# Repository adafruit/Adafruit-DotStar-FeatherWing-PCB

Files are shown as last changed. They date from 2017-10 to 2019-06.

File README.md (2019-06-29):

## Adafruit DotStar FeatherWing PCB

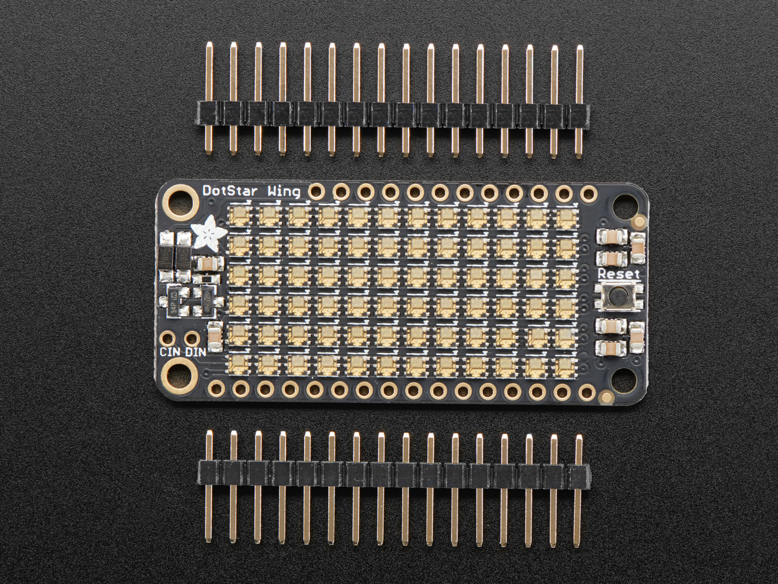
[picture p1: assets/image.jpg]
<a href="http://www.adafruit.com/products/3449"><br/>
Click here to purchase one from the Adafruit shop</a>

PCB files for the Adafruit DotStar FeatherWing. Format is EagleCAD schematic and board layout

For more details, check out the product page at
* http://www.adafruit.com/products/3449

### Description

A Feather board without ambition is a Feather board without FeatherWings! This is the DotStar FeatherWing, a 6x12 RGB LED Add-on For All Feather Boards! Using our Feather Stacking Headers or Feather Female Headers you can connect a FeatherWing on top or bottom of your Feather board and make your Feather board strut like a peacock at a rave.

Put on your sunglasses before staring into these 72 configurable RGB LEDs, they are super bright! Arranged in a 6x12 matrix, each 2mm by 2mm sized RGB pixel is individually addressable. Only two pins are required to control all the LEDs. On the bottom we have jumpers for the Data and Clock lines so you can change them from the defaults. Works with any/all of our Feathers! You can cut the default jumper traces and use any pins you like

To make it easy to start, the LEDs are by default powered from either the USB power line or Battery power line, whichever is higher. Two Schottky diodes are used to switch between the two. This power arrangement is able to handle 1 Amp of constant current draw and maybe 2A peak, so not a good way to make a flashlight. It's better for colorful effects. A power MOSFET is set up and connected to the ENABLE pin on the Feather so that when the Feather is disabled, the wing will also cut power.

### License

Adafruit invests time and resources providing this open source design, please support Adafruit and open-source hardware by purchasing products from [Adafruit](https://www.adafruit.com)!

Designed by Limor Fried/Ladyada for Adafruit Industries.

Creative Commons Attribution/Share-Alike, all text above must be included in any redistribution. See license.txt for additional details.

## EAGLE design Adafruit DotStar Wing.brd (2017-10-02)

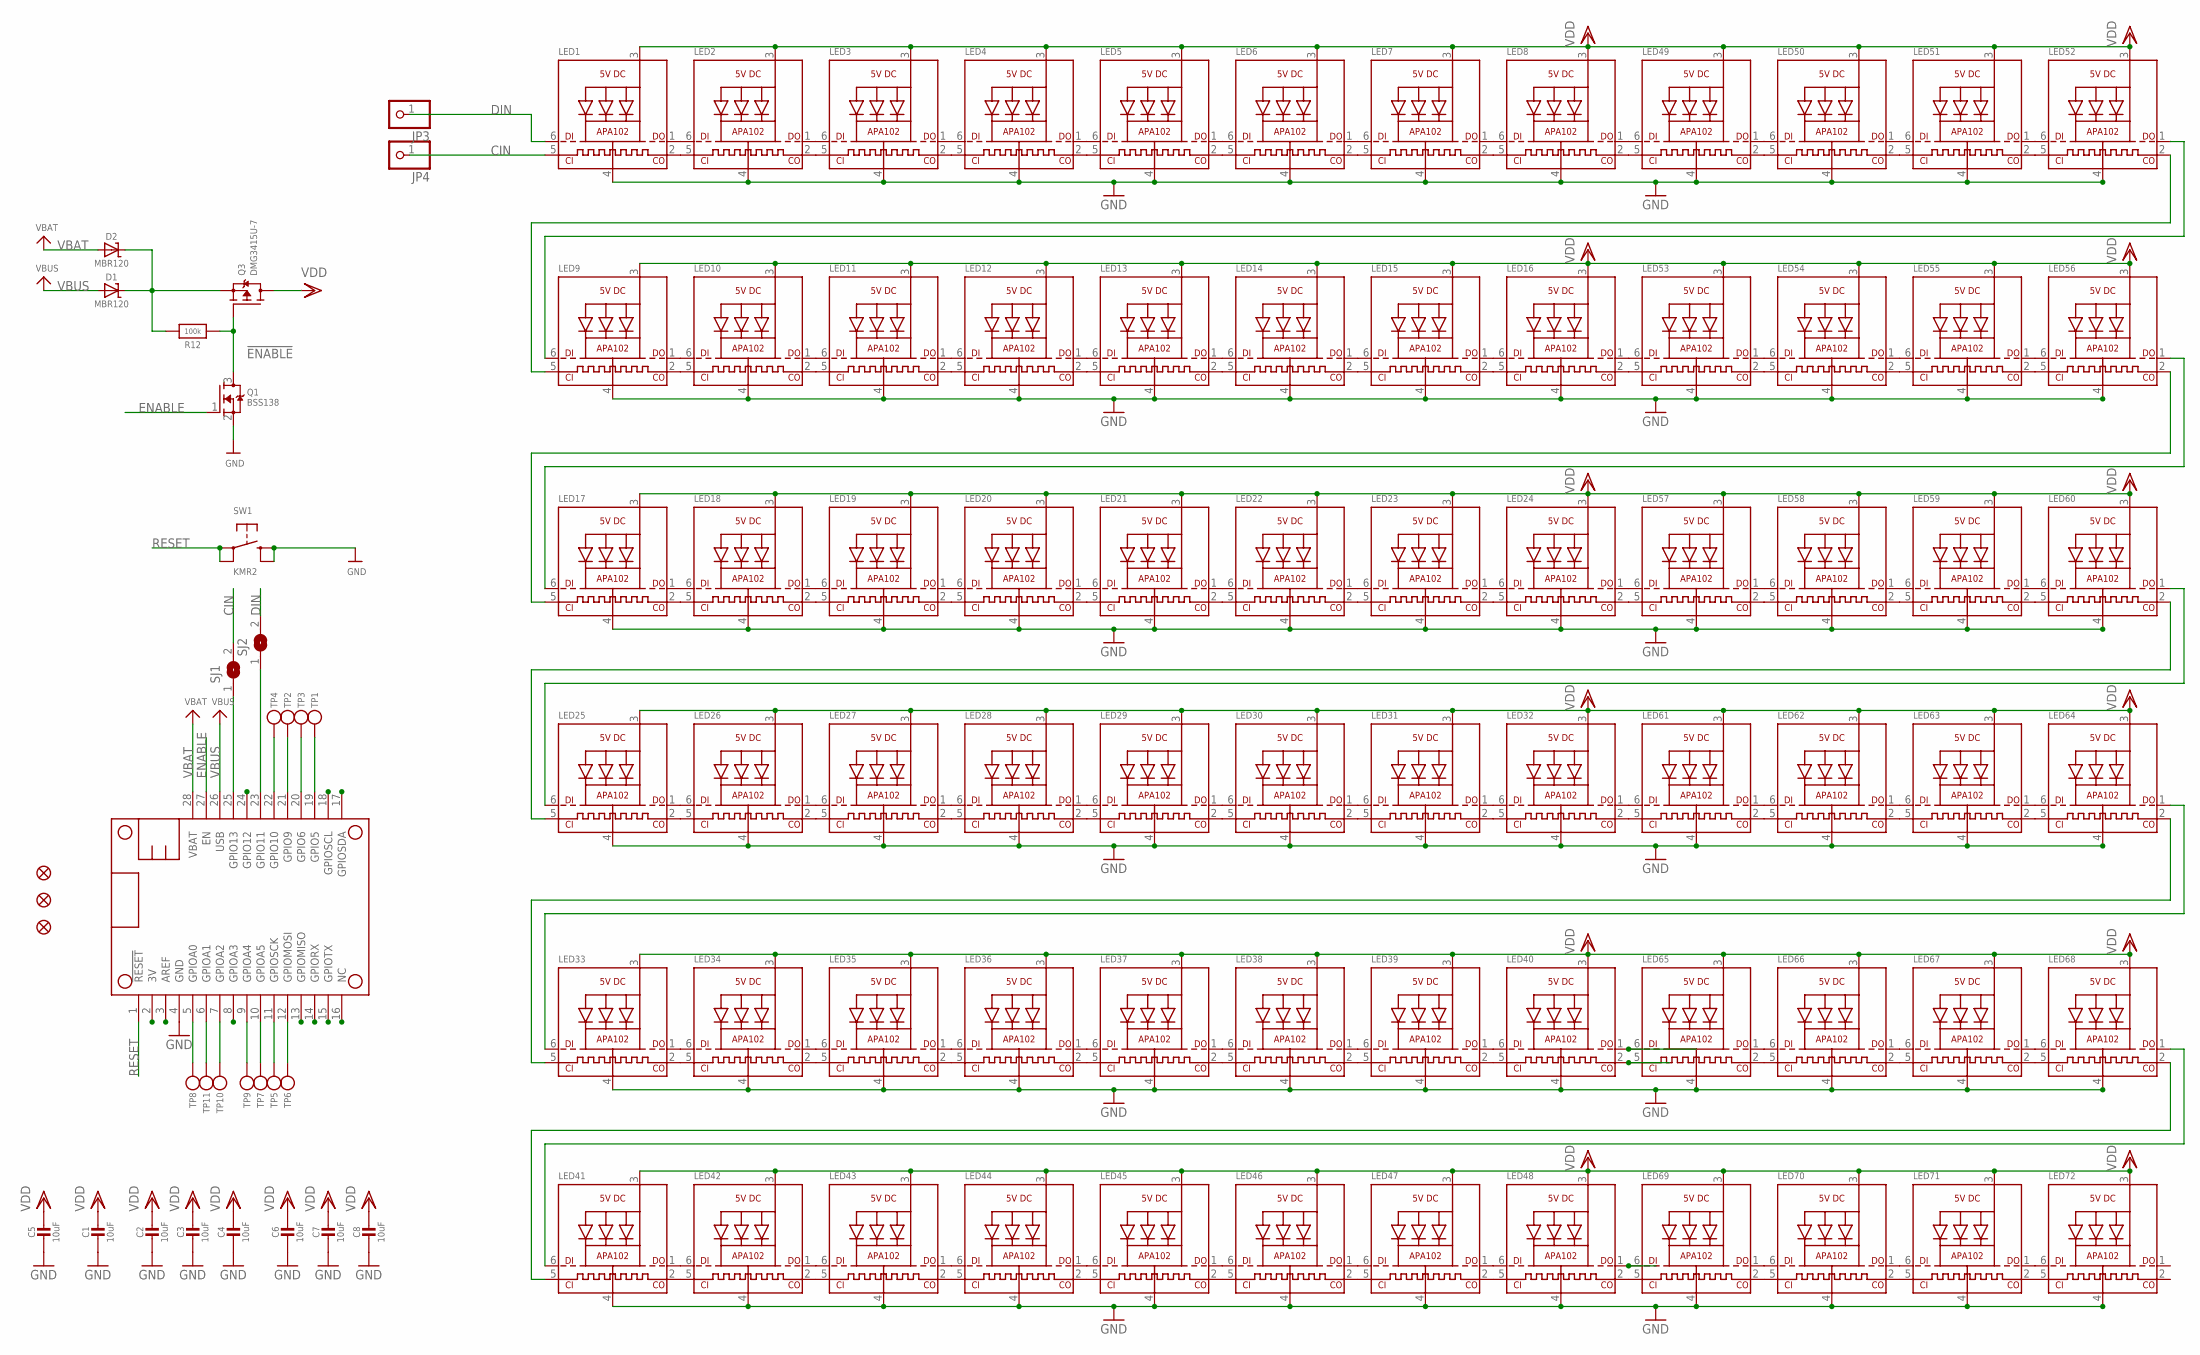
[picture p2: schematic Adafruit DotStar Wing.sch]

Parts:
C1, C2, C3, C4, C5, C6, C7, C8: 10uF; 0805-NO
D1, D2: MBR120; SOD-123
FID1, FID2, FID3: FIDUCIAL_1MM
JP3, JP4: HEADER-1X1ROUND; 1X01_ROUND
LED1, LED2, LED3, LED4, LED5, LED6, LED7, LED8, LED9, LED10, LED11, LED12, LED13, LED14, LED15, LED16, LED17, LED18, LED19, LED20, LED21, LED22, LED23, LED24, LED25, LED26, LED27, LED28, LED29, LED30, LED31, LED32, LED33, LED34, LED35, LED36, LED37, LED38, LED39, LED40, LED41, LED42, LED43, LED44, LED45, LED46, LED47, LED48, LED49, LED50, LED51, LED52, LED53, LED54, LED55, LED56, LED57, LED58, LED59, LED60, LED61, LED62, LED63, LED64, LED65, LED66, LED67, LED68, LED69, LED70, LED71, LED72: APA1022020; APA102_2020
MS1: FEATHERWING
Q1: BSS138; SOT23-WIDE
Q3: DMG3415U-7; SOT23-WIDE
R12: 100k; 0603-NO
SJ1, SJ2: SOLDERJUMPERCLOSED; SOLDERJUMPER_CLOSEDWIRE
SW1: KMR2; BTN_KMR2_4.6X2.8
TP1, TP2, TP3, TP4, TP5, TP6, TP7, TP8, TP9, TP10, TP11: TESTPOINT1.5X2.0MM_NOCREAM; PAD-1.5X2.0

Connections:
3V: MS1.2 (3V)
!ENABLE: Q1.3 (D), Q3.1 (G), R12.1
A0: MS1.5 (GPIOA0), TP8.P$1
A1: MS1.6 (GPIOA1), TP11.P$1
A2: MS1.7 (GPIOA2), TP10.P$1
A3: MS1.8 (GPIOA3)
A4: MS1.9 (GPIOA4), TP9.P$1
A5: MS1.10 (GPIOA5), TP7.P$1
AREF: MS1.3 (AREF)
CIN: JP4.1, LED1.5 (CKI), SJ1.2
DIN: JP3.1, LED1.6 (DI), SJ2.2
ENABLE: MS1.27 (EN), Q1.1 (G)
G: MS1.16 (NC)
GND: C1.2, C2.2, C3.2, C4.2, C5.2, C6.2, C7.2, C8.2, LED1.4 (GND), LED2.4 (GND), LED3.4 (GND), LED4.4 (GND), LED5.4 (GND), LED6.4 (GND), LED7.4 (GND), LED8.4 (GND), LED9.4 (GND), LED10.4 (GND), LED11.4 (GND), LED12.4 (GND), LED13.4 (GND), LED14.4 (GND), LED15.4 (GND), LED16.4 (GND), LED17.4 (GND), LED18.4 (GND), LED19.4 (GND), LED20.4 (GND), LED21.4 (GND), LED22.4 (GND), LED23.4 (GND), LED24.4 (GND), LED25.4 (GND), LED26.4 (GND), LED27.4 (GND), LED28.4 (GND), LED29.4 (GND), LED30.4 (GND), LED31.4 (GND), LED32.4 (GND), LED33.4 (GND), LED34.4 (GND), LED35.4 (GND), LED36.4 (GND), LED37.4 (GND), LED38.4 (GND), LED39.4 (GND), LED40.4 (GND), LED41.4 (GND), LED42.4 (GND), LED43.4 (GND), LED44.4 (GND), LED45.4 (GND), LED46.4 (GND), LED47.4 (GND), LED48.4 (GND), LED49.4 (GND), LED50.4 (GND), LED51.4 (GND), LED52.4 (GND), LED53.4 (GND), LED54.4 (GND), LED55.4 (GND), LED56.4 (GND), LED57.4 (GND), LED58.4 (GND), LED59.4 (GND), LED60.4 (GND), LED61.4 (GND), LED62.4 (GND), LED63.4 (GND), LED64.4 (GND), LED65.4 (GND), LED66.4 (GND), LED67.4 (GND), LED68.4 (GND), LED69.4 (GND), LED70.4 (GND), LED71.4 (GND), LED72.4 (GND), MS1.4 (GND), Q1.2 (S), SW1.B (S), SW1.B' (S1)
H: MS1.19 (GPIO5), TP1.P$1
I: MS1.20 (GPIO6), TP3.P$1
J: MS1.21 (GPIO9), TP2.P$1
K: MS1.22 (GPIO10), TP4.P$1
L: MS1.23 (GPIO11), SJ2.1
M: MS1.24 (GPIO12)
MISO: MS1.13 (GPIOMISO)
MOSI: MS1.12 (GPIOMOSI), TP6.P$1
N: MS1.25 (GPIO13), SJ1.1
unnamed: LED1.1 (DO), LED2.6 (DI)
unnamed: LED1.2 (CKO), LED2.5 (CKI)
unnamed: LED2.1 (DO), LED3.6 (DI)
unnamed: LED2.2 (CKO), LED3.5 (CKI)
unnamed: LED3.1 (DO), LED4.6 (DI)
unnamed: LED3.2 (CKO), LED4.5 (CKI)
unnamed: LED4.1 (DO), LED5.6 (DI)
unnamed: LED4.2 (CKO), LED5.5 (CKI)
unnamed: LED5.1 (DO), LED6.6 (DI)
unnamed: LED5.2 (CKO), LED6.5 (CKI)
unnamed: LED6.1 (DO), LED7.6 (DI)
unnamed: LED6.2 (CKO), LED7.5 (CKI)
unnamed: LED7.1 (DO), LED8.6 (DI)
unnamed: LED7.2 (CKO), LED8.5 (CKI)
unnamed: LED9.1 (DO), LED10.6 (DI)
unnamed: LED9.2 (CKO), LED10.5 (CKI)
unnamed: LED10.1 (DO), LED11.6 (DI)
unnamed: LED10.2 (CKO), LED11.5 (CKI)
unnamed: LED11.1 (DO), LED12.6 (DI)
unnamed: LED11.2 (CKO), LED12.5 (CKI)
unnamed: LED12.1 (DO), LED13.6 (DI)
unnamed: LED12.2 (CKO), LED13.5 (CKI)
unnamed: LED13.1 (DO), LED14.6 (DI)
unnamed: LED13.2 (CKO), LED14.5 (CKI)
unnamed: LED14.1 (DO), LED15.6 (DI)
unnamed: LED14.2 (CKO), LED15.5 (CKI)
unnamed: LED15.1 (DO), LED16.6 (DI)
unnamed: LED15.2 (CKO), LED16.5 (CKI)
unnamed: LED17.1 (DO), LED18.6 (DI)
unnamed: LED17.2 (CKO), LED18.5 (CKI)
unnamed: LED18.1 (DO), LED19.6 (DI)
unnamed: LED18.2 (CKO), LED19.5 (CKI)
unnamed: LED19.1 (DO), LED20.6 (DI)
unnamed: LED19.2 (CKO), LED20.5 (CKI)
unnamed: LED20.1 (DO), LED21.6 (DI)
unnamed: LED20.2 (CKO), LED21.5 (CKI)
unnamed: LED21.1 (DO), LED22.6 (DI)
unnamed: LED21.2 (CKO), LED22.5 (CKI)
unnamed: LED22.1 (DO), LED23.6 (DI)
unnamed: LED22.2 (CKO), LED23.5 (CKI)
unnamed: LED23.1 (DO), LED24.6 (DI)
unnamed: LED23.2 (CKO), LED24.5 (CKI)
unnamed: LED25.1 (DO), LED26.6 (DI)
unnamed: LED25.2 (CKO), LED26.5 (CKI)
unnamed: LED26.1 (DO), LED27.6 (DI)
unnamed: LED26.2 (CKO), LED27.5 (CKI)
unnamed: LED27.1 (DO), LED28.6 (DI)
unnamed: LED27.2 (CKO), LED28.5 (CKI)
unnamed: LED28.1 (DO), LED29.6 (DI)
unnamed: LED28.2 (CKO), LED29.5 (CKI)
unnamed: LED29.1 (DO), LED30.6 (DI)
unnamed: LED29.2 (CKO), LED30.5 (CKI)
unnamed: LED30.1 (DO), LED31.6 (DI)
unnamed: LED30.2 (CKO), LED31.5 (CKI)
unnamed: LED31.1 (DO), LED32.6 (DI)
unnamed: LED31.2 (CKO), LED32.5 (CKI)
unnamed: LED33.1 (DO), LED34.6 (DI)
unnamed: LED33.2 (CKO), LED34.5 (CKI)
unnamed: LED34.1 (DO), LED35.6 (DI)
unnamed: LED34.2 (CKO), LED35.5 (CKI)
unnamed: LED35.1 (DO), LED36.6 (DI)
unnamed: LED35.2 (CKO), LED36.5 (CKI)
unnamed: LED36.1 (DO), LED37.6 (DI)
unnamed: LED36.2 (CKO), LED37.5 (CKI)
unnamed: LED37.1 (DO), LED38.6 (DI)
unnamed: LED37.2 (CKO), LED38.5 (CKI)
unnamed: LED38.1 (DO), LED39.6 (DI)
unnamed: LED38.2 (CKO), LED39.5 (CKI)
unnamed: LED39.1 (DO), LED40.6 (DI)
unnamed: LED39.2 (CKO), LED40.5 (CKI)
unnamed: LED41.1 (DO), LED42.6 (DI)
unnamed: LED41.2 (CKO), LED42.5 (CKI)
unnamed: LED42.1 (DO), LED43.6 (DI)
unnamed: LED42.2 (CKO), LED43.5 (CKI)
unnamed: LED43.1 (DO), LED44.6 (DI)
unnamed: LED43.2 (CKO), LED44.5 (CKI)
unnamed: LED44.1 (DO), LED45.6 (DI)
unnamed: LED44.2 (CKO), LED45.5 (CKI)
unnamed: LED45.1 (DO), LED46.6 (DI)
unnamed: LED45.2 (CKO), LED46.5 (CKI)
unnamed: LED46.1 (DO), LED47.6 (DI)
unnamed: LED46.2 (CKO), LED47.5 (CKI)
unnamed: LED47.1 (DO), LED48.6 (DI)
unnamed: LED47.2 (CKO), LED48.5 (CKI)
unnamed: LED8.1 (DO), LED49.6 (DI)
unnamed: LED8.2 (CKO), LED49.5 (CKI)
unnamed: LED49.1 (DO), LED50.6 (DI)
unnamed: LED49.2 (CKO), LED50.5 (CKI)
unnamed: LED50.1 (DO), LED51.6 (DI)
unnamed: LED50.2 (CKO), LED51.5 (CKI)
unnamed: LED51.1 (DO), LED52.6 (DI)
unnamed: LED51.2 (CKO), LED52.5 (CKI)
unnamed: LED16.1 (DO), LED53.6 (DI)
unnamed: LED16.2 (CKO), LED53.5 (CKI)
unnamed: LED53.1 (DO), LED54.6 (DI)
unnamed: LED53.2 (CKO), LED54.5 (CKI)
unnamed: LED54.1 (DO), LED55.6 (DI)
unnamed: LED54.2 (CKO), LED55.5 (CKI)
unnamed: LED55.1 (DO), LED56.6 (DI)
unnamed: LED55.2 (CKO), LED56.5 (CKI)
unnamed: LED24.1 (DO), LED57.6 (DI)
unnamed: LED24.2 (CKO), LED57.5 (CKI)
unnamed: LED57.1 (DO), LED58.6 (DI)
unnamed: LED57.2 (CKO), LED58.5 (CKI)
unnamed: LED58.1 (DO), LED59.6 (DI)
unnamed: LED58.2 (CKO), LED59.5 (CKI)
unnamed: LED59.1 (DO), LED60.6 (DI)
unnamed: LED59.2 (CKO), LED60.5 (CKI)
unnamed: LED61.1 (DO), LED62.6 (DI)
unnamed: LED61.2 (CKO), LED62.5 (CKI)
unnamed: LED62.1 (DO), LED63.6 (DI)
unnamed: LED62.2 (CKO), LED63.5 (CKI)
unnamed: LED9.5 (CKI), LED52.2 (CKO)
unnamed: LED17.6 (DI), LED56.1 (DO)
unnamed: LED17.5 (CKI), LED56.2 (CKO)
unnamed: LED25.5 (CKI), LED60.2 (CKO)
unnamed: LED33.6 (DI), LED64.1 (DO)
unnamed: LED63.1 (DO), LED64.6 (DI)
unnamed: LED63.2 (CKO), LED64.5 (CKI)
unnamed: LED65.1 (DO), LED66.6 (DI)
unnamed: LED48.1 (DO), LED69.6 (DI)
unnamed: LED41.5 (CKI), LED68.2 (CKO)
unnamed: LED41.6 (DI), LED68.1 (DO)
unnamed: LED65.2 (CKO), LED66.5 (CKI)
unnamed: LED66.1 (DO), LED67.6 (DI)
unnamed: LED66.2 (CKO), LED67.5 (CKI)
unnamed: LED67.1 (DO), LED68.6 (DI)
unnamed: LED67.2 (CKO), LED68.5 (CKI)
unnamed: LED69.1 (DO), LED70.6 (DI)
unnamed: LED69.2 (CKO), LED70.5 (CKI)
unnamed: LED70.1 (DO), LED71.6 (DI)
unnamed: LED70.2 (CKO), LED71.5 (CKI)
unnamed: LED71.1 (DO), LED72.6 (DI)
unnamed: LED71.2 (CKO), LED72.5 (CKI)
unnamed: LED9.6 (DI), LED52.1 (DO)
unnamed: D1.C, D2.C, Q3.2 (S), R12.2
unnamed: LED32.2 (CKO), LED61.5 (CKI)
unnamed: LED32.1 (DO), LED61.6 (DI)
unnamed: LED25.6 (DI), LED60.1 (DO)
unnamed: LED33.5 (CKI), LED64.2 (CKO)
unnamed: LED48.2 (CKO), LED69.5 (CKI)
unnamed: LED40.2 (CKO), LED65.5 (CKI)
unnamed: LED40.1 (DO), LED65.6 (DI)
RESET: MS1.1 (!RESET), SW1.A, SW1.A' (P1)
RX: MS1.14 (GPIORX)
SCK: MS1.11 (GPIOSCK), TP5.P$1
SCL: MS1.18 (GPIOSCL)
SDA: MS1.17 (GPIOSDA)
TX: MS1.15 (GPIOTX)
VBAT: D2.A, MS1.28 (VBAT)
VBUS: D1.A, MS1.26 (USB)
VDD: C1.1, C2.1, C3.1, C4.1, C5.1, C6.1, C7.1, C8.1, LED1.3 (VDD), LED2.3 (VDD), LED3.3 (VDD), LED4.3 (VDD), LED5.3 (VDD), LED6.3 (VDD), LED7.3 (VDD), LED8.3 (VDD), LED9.3 (VDD), LED10.3 (VDD), LED11.3 (VDD), LED12.3 (VDD), LED13.3 (VDD), LED14.3 (VDD), LED15.3 (VDD), LED16.3 (VDD), LED17.3 (VDD), LED18.3 (VDD), LED19.3 (VDD), LED20.3 (VDD), LED21.3 (VDD), LED22.3 (VDD), LED23.3 (VDD), LED24.3 (VDD), LED25.3 (VDD), LED26.3 (VDD), LED27.3 (VDD), LED28.3 (VDD), LED29.3 (VDD), LED30.3 (VDD), LED31.3 (VDD), LED32.3 (VDD), LED33.3 (VDD), LED34.3 (VDD), LED35.3 (VDD), LED36.3 (VDD), LED37.3 (VDD), LED38.3 (VDD), LED39.3 (VDD), LED40.3 (VDD), LED41.3 (VDD), LED42.3 (VDD), LED43.3 (VDD), LED44.3 (VDD), LED45.3 (VDD), LED46.3 (VDD), LED47.3 (VDD), LED48.3 (VDD), LED49.3 (VDD), LED50.3 (VDD), LED51.3 (VDD), LED52.3 (VDD), LED53.3 (VDD), LED54.3 (VDD), LED55.3 (VDD), LED56.3 (VDD), LED57.3 (VDD), LED58.3 (VDD), LED59.3 (VDD), LED60.3 (VDD), LED61.3 (VDD), LED62.3 (VDD), LED63.3 (VDD), LED64.3 (VDD), LED65.3 (VDD), LED66.3 (VDD), LED67.3 (VDD), LED68.3 (VDD), LED69.3 (VDD), LED70.3 (VDD), LED71.3 (VDD), LED72.3 (VDD), Q3.3 (D)

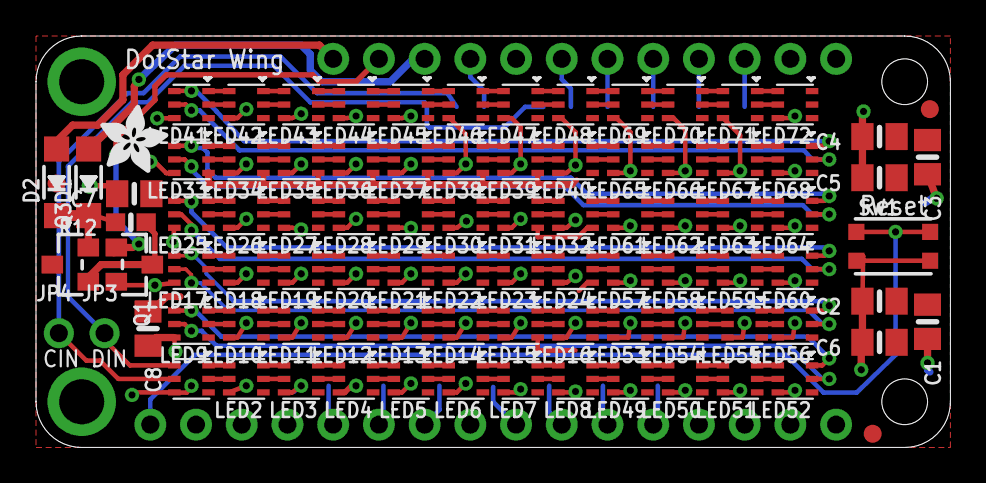
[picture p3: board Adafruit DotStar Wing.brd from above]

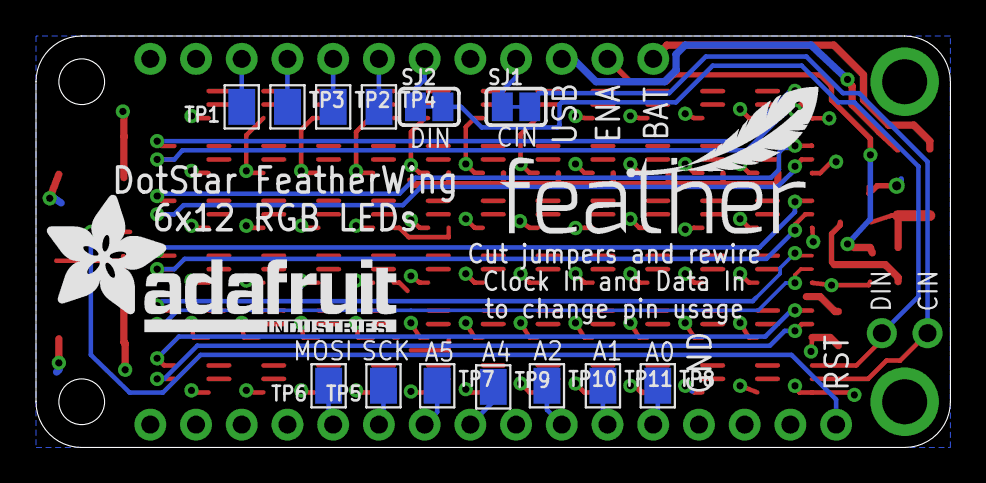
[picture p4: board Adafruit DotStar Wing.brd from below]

Board: 2 copper layers, 50.8 x 22.9 mm, 108 parts (15 on the bottom side), 165 nets.

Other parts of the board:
U$1: ADAFRUIT_TEXT_20MM
U$8: FEATHERLOGO_MED
U$9: ADAFRUIT_3.5MM

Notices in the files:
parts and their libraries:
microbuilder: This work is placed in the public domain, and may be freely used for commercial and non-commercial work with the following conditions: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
